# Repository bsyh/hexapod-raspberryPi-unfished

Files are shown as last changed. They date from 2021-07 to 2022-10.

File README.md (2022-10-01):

# hexapod-raspberryPi

hexapod raspberry pi

This is a Hexapod raspberry Pi B4 project, originated by `SmallpTsai`.
`SmallpTsai` drove it via 7697. 
In this project, we will port the driver to Raspberry Pi 4B and re-design hardware components. 

## Brief introduction

* **Remote control** is done via `WIFI Socket` or `USB joystick`
* It has 6 legs, each leg has 3 joints. So there are total of `18` **Servo motors** (TowerPro `MG92B`)
* `Raspberry Pi 4B` only provides 1 hardwire **PWM control**, so `PCA9685 control board` x 2 with the integrated step-down regulator are used to control these servo motors through `IIC`.
* **Power** comes from a `3S Lipo battery (11.1v)`. Also, 3 `mini560 DC-DC` step-down voltage regulators (5V 5A-max) are used, one to power RaspbPi, the other 2 are to power PCA9685 control boards.
* The **body** is 3D printed with `Somos® Imagine 8000` through a third-party 3D printing service.  
* **Angle sensor** `WIT JY61P` connects to RaspbPi through `IIC`.
* Followed by `SmallpTsai`, everything (3D STL, source code) is included in the project under **GPL license**.

## Skill requirement

If you want to make one hexapod by yourself. You should at least know how to:

* Mechanism part
    * Use `3D printer` to print a model.
    * Able to adjust the 3D model to fit your custom need.
* Electronics
    * Soldering power cord
    * How to use/charge/store `LIPO batteries`
* Software
    * Use `RaspbPi OS (Buster)` 
    * Use `Python 3`

## Table of Content

1. [Mechanism](mechanism/) - How to build the body
1. [Software](software/) - The software running on RaspbPi

## Function showcases

https://user-images.githubusercontent.com/45125740/167921903-36e5d80f-a7ff-4572-bfeb-e2b2ff5b1781.mp4

https://user-images.githubusercontent.com/45125740/167921833-c19824d3-37fa-4d62-b973-f710111ed2f8.mp4

leg testing

https://user-images.githubusercontent.com/45125740/167921867-10a3a2ef-41d6-4d2f-a60c-628305d9845e.mp4

Angle sensor

https://user-images.githubusercontent.com/45125740/167920268-071bab98-9ca7-449c-ad2f-77d9b62e90ba.mp4

complete spider

https://user-images.githubusercontent.com/45125740/167921947-8c45f19b-c2c6-4d83-9618-dd7769f0ed23.mp4

walking mode

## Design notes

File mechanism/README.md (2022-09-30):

Note: some 3d printer has a lower bound of thickness, some model are fixed with incresing smallest thickness plane.

# Mechanism

Body

## Bill of Materials

[BOM](BOM.md)

## Leg Assemble

LegAssemble

Please check [Leg Assemble](LEG.md) for more detail instructions

Leg assembly instruction video https://youtu.be/oaAE5fC09KQ is also available.


> Note. Total 6 Legs are required.

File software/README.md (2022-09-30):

# Software
## Architecture
* `smoveServer.py`: opens a port, reads signals as movement command 
* `joystick.py`: connects to a joystick, sends commands to servo_server port
* `realsense.py`: open Intel realsense D435i port

## Main
run start.sh to open all components

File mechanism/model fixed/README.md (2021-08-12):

For some types of 3D printers, there might be a requirement of minimum thickness at the edges that connect surfaces. 
If you find that components crack due to the thickness issue, try the fixed model in this folder.

`body_center.stl`: redesign a flat surface for angle sensor.

`body_top.stl`: added 4 holes for RaspbPi assembling.

`foot_ground_1.STL` & `foot_ground_2.STL` & `foot_ground_3.STL`: more styles

`thigh_bottom.stl `: increased thickness near screw hole where 3D printer may fail to print

`leg_bottom.STL `: increased thickness near screw hole where 3D printer may fail to print

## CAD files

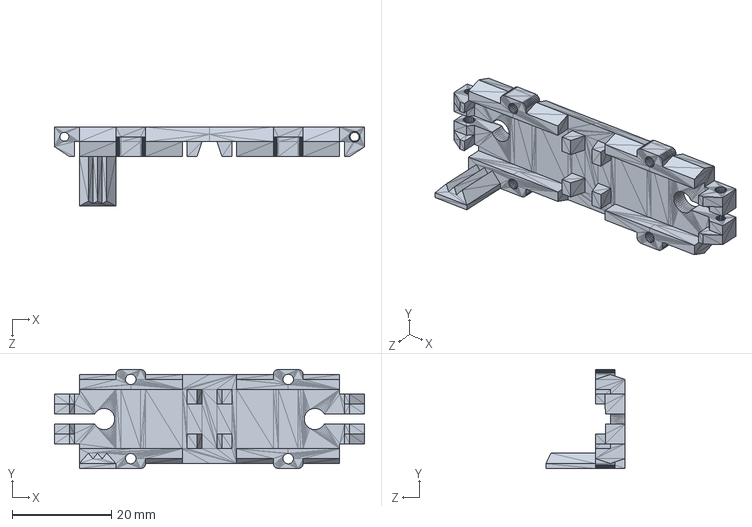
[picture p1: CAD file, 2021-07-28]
mechanism/files/leg_bottom_fixed.SLDPRT
62.6 x 20.0 x 16.0 mm

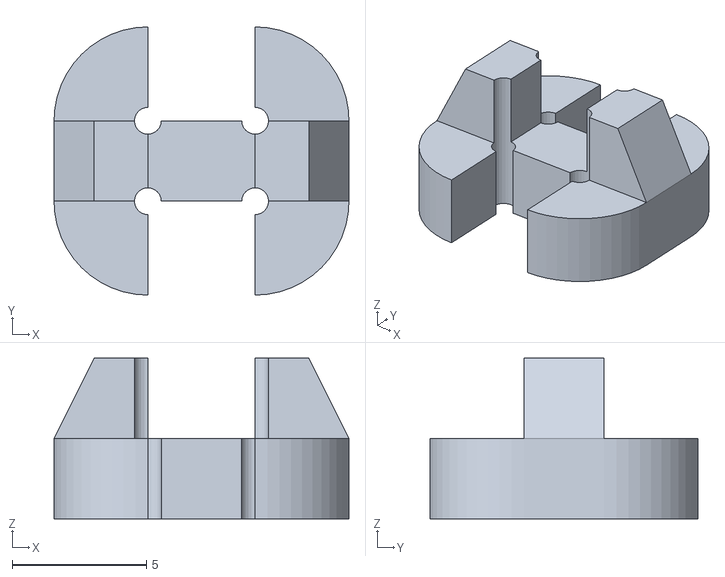
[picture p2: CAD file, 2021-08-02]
mechanism/foot_tip.stl
11.0 x 10.0 x 6.00

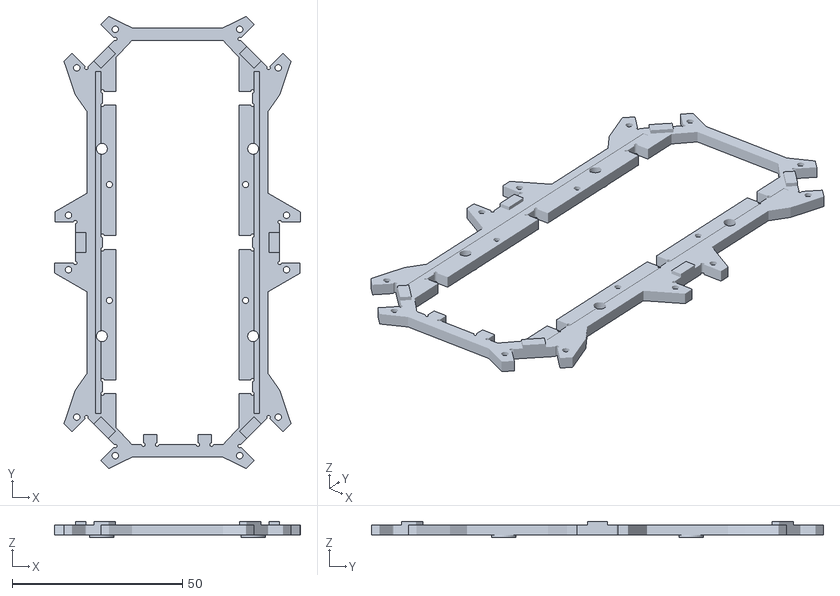
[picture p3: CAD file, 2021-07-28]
mechanism/model fixed/body_top.stl
72.3 x 132.7 x 4.70

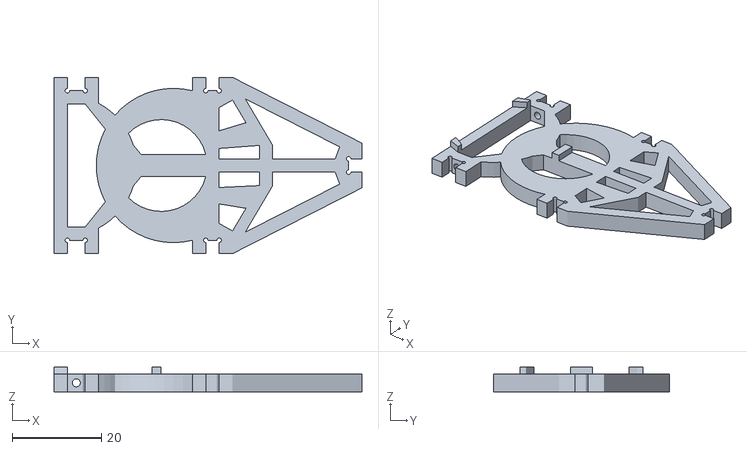
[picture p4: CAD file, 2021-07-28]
mechanism/model fixed/foot_ground_3.STL
69.0 x 39.5 x 5.50

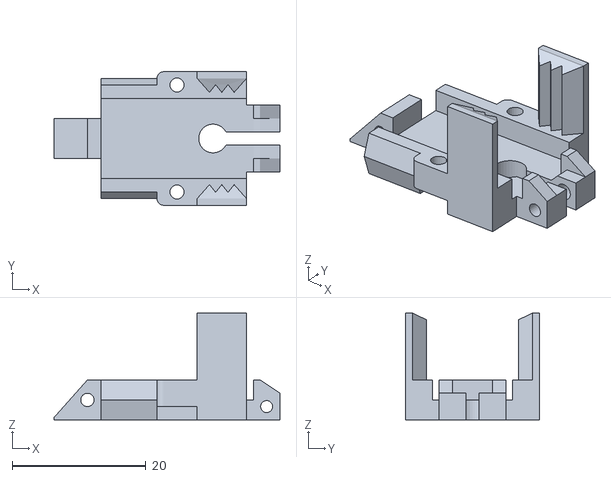
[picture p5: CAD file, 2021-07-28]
mechanism/model fixed/thigh_bottom.stl
33.8 x 20.0 x 16.0

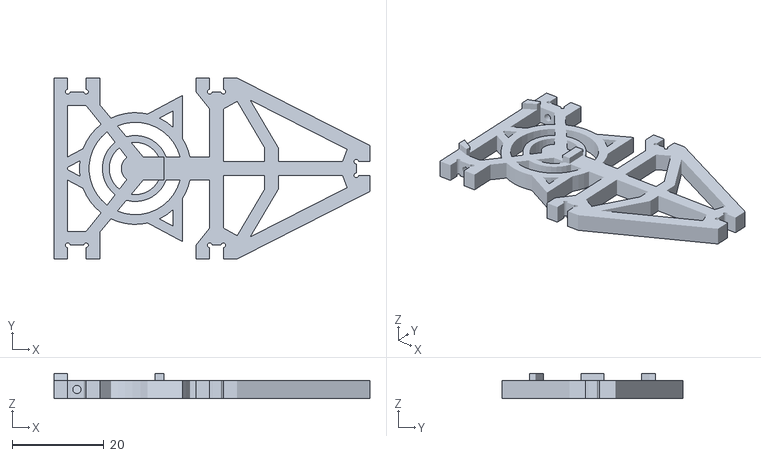
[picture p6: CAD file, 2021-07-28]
mechanism/model fixed/foot_ground_1.STL
69.0 x 39.5 x 5.50

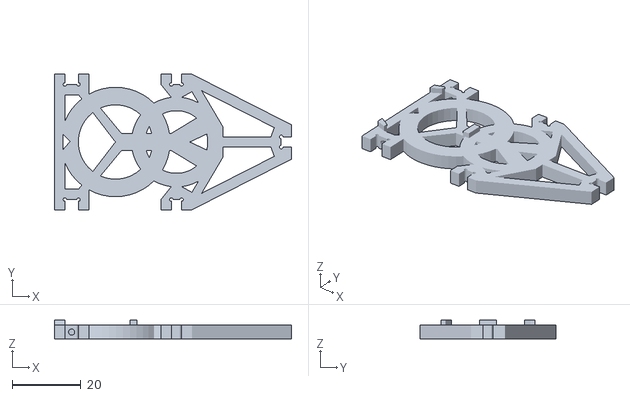
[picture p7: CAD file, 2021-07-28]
mechanism/model fixed/foot_ground_2.STL
69.0 x 39.5 x 5.50

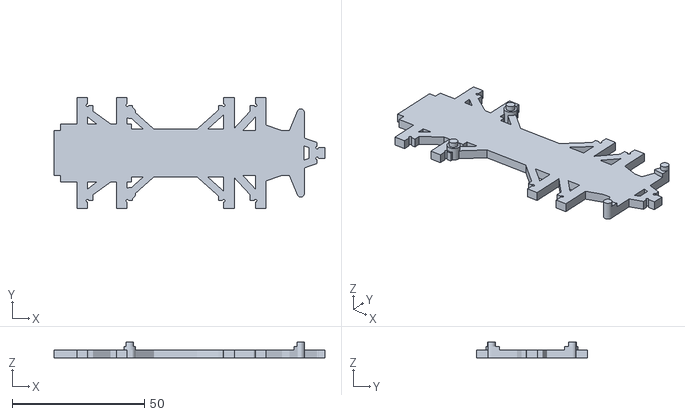
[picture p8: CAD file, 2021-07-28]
mechanism/model fixed/body_center.stl
102.3 x 42.0 x 6.00

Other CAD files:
mechanism/model fixed/leg_bottom.STL

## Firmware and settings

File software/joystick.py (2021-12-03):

#!/usr/bin/env python3
# encoding: utf-8

import os
import time
import json
import pygame
import math
import requests
import socket

address = ('127.0.0.1', 3982)  # 服务端地址和端口
s = socket.socket(socket.AF_INET, socket.SOCK_DGRAM)
print('[Port Opened] ',address[0],':',address[1])
#trigger = [motor,motor1,motor2,motor3]
#s.sendto(trigger.encode(), address)

turnningSpeedSmall=60
turnningSpeed=80
turnningSpeedMax=90
servoStep=2
key_map = {"PSB_CROSS":2, "PSB_CIRCLE":1, "PSB_SQUARE":3, "PSB_TRIANGLE":0,
        "PSB_L1": 4, "PSB_R1":5, "PSB_L2":6, "PSB_R2":7,
        "PSB_SELECT":8, "PSB_START":9, "PSB_L3":10, "PSB_R3":11};

os.environ["SDL_VIDEODRIVER"] = "dummy"
pygame.display.init()
pygame.joystick.init()

c=0
if False and pygame.joystick.get_count() > 0 :
    js=pygame.joystick.Joystick(0)
    js.init()
    jsName = js.get_name()
    print("Name of the joystick:", jsName)
    jsAxes=js.get_numaxes()
    print("Number of axif:",jsAxes)
    jsButtons=js.get_numbuttons()
    print("Number of buttons:", jsButtons);
    jsBall=js.get_numballs()
    print("Numbe of balls:", jsBall)
    jsHat= js.get_numhats()
    print("Number of hats:", jsHat)

connected = False
trigger = [0,0,0,0,310,168]
while True:
    trigger = [0,0,0,0,trigger[4],trigger[5]]
    if os.path.exists("/dev/input/js0") is True:
        if connected is False:
            jscount =  pygame.joystick.get_count()
            if jscount > 0:
                try:
                    js=pygame.joystick.Joystick(0)
                    js.init()
                    connected = True
                except Exception as e:
                    print(e)
            else:
                pygame.joystick.quit()
    else:
        if connected is True:
            connected = False
            js.quit()
            pygame.joystick.quit()
    if connected is True:
        pygame.event.pump()
        try:
            if js.get_button(key_map["PSB_R1"]) :
                print("PSB_R1")
                trigger[4]+=servoStep
                trigger[5]-=servoStep
            if js.get_button(key_map["PSB_L1"])  :
                print("PSB_L1")
                trigger[4]-=servoStep
                trigger[5]-=servoStep
            if js.get_button(key_map["PSB_SQUARE"]) :
                print("PSB_SQUARE")
                trigger[0]-=turnningSpeed
                trigger[1]+=turnningSpeed
                trigger[2]+=turnningSpeed
                trigger[3]-=turnningSpeed
            if js.get_button(key_map["PSB_CIRCLE"]) :
                print("PSB_CIRCLE")
                trigger[0]+=turnningSpeed
                trigger[1]-=turnningSpeed
                trigger[2]-=turnningSpeed
                trigger[3]+=turnningSpeed
            if js.get_button(key_map["PSB_R2"]) :
                print("PSB_R2")
                trigger[4]+=servoStep
                trigger[5]+=servoStep
            if js.get_button(key_map["PSB_L2"]) :
                print("PSB_L2")
                trigger[4]-=servoStep
                trigger[5]+=servoStep
            if js.get_button(key_map["PSB_TRIANGLE"]) :
                print("PSB_TRIANGLE")
                for i in range(4):
                    trigger[i]+=turnningSpeed
            if js.get_button(key_map["PSB_CROSS"]) :
               print("PSB_CROSS")
               for i in range(4):
                    trigger[i]-=turnningSpeed

            if js.get_button(key_map["PSB_L3"]) :
                print("PSB_L3")
            if js.get_button(key_map["PSB_R3"]) :
                print("PSB_R3")


            hat = js.get_hat(0)
            #print('(hat)',hat)
            if hat[0] > 0 :
                print("hat[0] +++")
                trigger[0] = trigger[0]+turnningSpeed
                trigger[2] = trigger[2]+turnningSpeed
                trigger[3] = trigger[3]-turnningSpeed
                trigger[1] = trigger[1]-turnningSpeed

            if hat[0] < 0:
                print("hat[0] ---")
                trigger[0] = trigger[0]-turnningSpeed
                trigger[2] = trigger[2]-turnningSpeed
                trigger[3] = trigger[3]+turnningSpeed
                trigger[1] = trigger[1]+turnningSpeed

            if hat[1] > 0 :
                print("hat[1] +++")
                for i in range(4):
                    trigger[i]=trigger[i]+turnningSpeed


            if hat[1] < 0:
                print("hat[1] ---")
                for i in range(4):
                    trigger[i]=trigger[i]-turnningSpeed

            detect_lowerbound = 0.01
            lx = js.get_axis(0)
            ly = -1*js.get_axis(1)
            rx = js.get_axis(2)
            ry = -1*js.get_axis(3)
            if  -detect_lowerbound <lx <detect_lowerbound  :
                 pass
            else:
                print('axis_lx', lx)
                if lx<0:
                    trigger[0]=trigger[0]+lx*turnningSpeedSmall
                    trigger[2]=trigger[2]+lx*turnningSpeedSmall
                    trigger[1]=trigger[1]-lx*turnningSpeedSmall
                    trigger[3]=trigger[3]-lx*turnningSpeedSmall
                else:
                    trigger[0]=trigger[0]+lx*turnningSpeedSmall
                    trigger[2]=trigger[2]+lx*turnningSpeedSmall
                    trigger[1]=trigger[1]-lx*turnningSpeedSmall
                    trigger[3]=trigger[3]-lx*turnningSpeedSmall


            if  -detect_lowerbound <ly <detect_lowerbound  :
                pass
            else:
                print('axis_ly', ly)
                for i in range(4):
                    trigger[i]=trigger[i]+ly*turnningSpeed

            if  -detect_lowerbound <rx <detect_lowerbound  :
                pass
            else:
                print('axis_rx', rx)
                trigger[0]+=turnningSpeed*rx*1.3
                trigger[1]-=turnningSpeed*rx*1.3
                trigger[2]-=turnningSpeed*rx*1.3
                trigger[3]+=turnningSpeed*rx*1.3

            if  -detect_lowerbound <ry <detect_lowerbound  :
                 pass
            else:
                  print('axis_ry', ry)
                  for i in range(4):
                    trigger[i]+=turnningSpeed*ry


            if js.get_button(key_map["PSB_START"]):
                print('PSB_START')
        except Exception as e:
            print(e)
            connected = False
    for i in range(4):
        trigger[i] = (trigger[i])*1
        trigger[i] = max(min(trigger[i],turnningSpeedMax),-1*turnningSpeedMax)
    trigger[5] = max(min(trigger[5],330),155)
    trigger[4] = max(min(trigger[4],430),220)

    #print("Send ",trigger)
    s.sendto(str(trigger).encode(), address)
    time.sleep(0.06)
s.close()

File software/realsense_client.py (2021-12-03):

import cv2
import io
import socket
import struct
import time
import pickle
import zlib

client_socket = socket.socket(socket.AF_INET, socket.SOCK_STREAM)
client_socket.connect(('192.168.3.6', 8485))
connection = client_socket.makefile('wb')

cam = cv2.VideoCapture(1)

cam.set(3, 320);
cam.set(4, 240);

img_counter = 0

encode_param = [int(cv2.IMWRITE_JPEG_QUALITY), 90]

while True:
    ret, frame = cam.read()
    # cv2.imshow('frame',frame)
    result, frame = cv2.imencode('.jpg', frame, encode_param)
#    data = zlib.compress(pickle.dumps(frame, 0))
    data = pickle.dumps(frame, 0)
    size = len(data)


    print("{}: {}".format(img_counter, size))
    client_socket.sendall(struct.pack(">L", size) + data)
    img_counter += 1

cam.release()

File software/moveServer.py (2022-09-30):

#!/usr/bin/env python2
# -*- coding: utf-8 -*-

from LOBOROBOT import LOBOROBOT  # 载入机器人库
import  RPi.GPIO as GPIO
import os
import time
import sys
import socket





address = ('127.0.0.1', 3982)  # 服务端地址和端口
s = socket.socket(socket.AF_INET, socket.SOCK_DGRAM)
s.bind(address)
s.settimeout(1)
print('[Port Opened] ',address[0],':',address[1])
def main():
    clbrobot = LOBOROBOT() # 实例化机器人对象
    data=[0.0,0.0,0.0,0.0,0.0,0.0]
    while True:
        try:
            data, addr = s.recvfrom(1024)  # 返回数据和接入连接的（服务端）地址
            data = data.decode()
            data = eval(data)
            print('[Received]', data)
        except socket.timeout:
            for i in range(4):
                data[i]=0
            print('[Receiving]')

        for i in range(4):
            speed = data[i]
            if speed>0:

                clbrobot.MotorRun(i,'forward',speed)
            else:

                clbrobot.MotorRun(i,'backward',-1*speed)

        data[5] = max(min(data[5],310),155)
        data[4] = max(min(data[4],430),220)
        clbrobot.pwm.setPWM(10,0,data[4])
        clbrobot.pwm.setPWM(9,0,data[5])





main()
clbrobot.t_stop(0)
GPIO.cleanup()

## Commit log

2021-07-28 Add files via upload
    The joints are thickened
    [leg_bottom_fixed.SLDPRT, leg_bottom_fixed.STL]
2021-07-28 Delete electronics directory
    Delete PCB describtion
    [main.brd, main.sch, sub.brd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]
2021-07-28 fixed stl
    [body_center.stl, body_top.stl, foot_ground_1.STL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]
2021-08-02 Delete foot_tip.stl
    size does not match leg
    [foot_tip.stl]
2021-08-02 Add files via upload
    fixed size
    [foot_tip.stl]
